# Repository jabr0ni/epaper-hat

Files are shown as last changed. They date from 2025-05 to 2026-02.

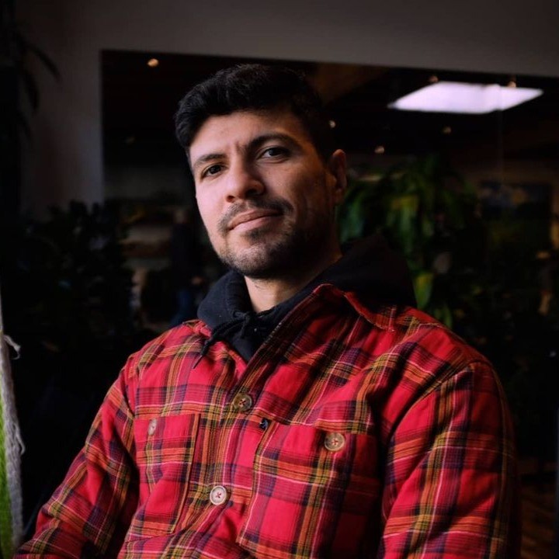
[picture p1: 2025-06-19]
Resources/1701730667659.jpg

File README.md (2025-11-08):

# E-Paper Business Card?

My idea is to create a type of business card with an e-paper display, where I can program some image/text content onto it. I also want to (in later revisions once the prototype is working) add a button on the back that can toggle to different images. Also have thought about adding one or two sensors (depending on space) such as a gyro and/or comms module. I plan on interfacing this with an STM32L4 MCU (have a Nucleo L433RC). Code for that has been started in this repo.

## PCB
This is my first PCB I've designed by myself from scratch, so any feedback is encouraged 😊
### Track layout


### Front + Back 3D



## BOM
| Reference | Qty | Value | Manufacturer Part No. |
|---|-----|---|---|
| C1, C2, C4, C5, C7, C9, C10 | 7 | 1u/50V | MBASU168AB5105KTNA01 |
| C3, C13 | 2 | 0.1u/50V | MAJCU168BB7104KTEA01 |
| C6, C8, C14 | 3 | 1u/25V | MAJCT168BB7105KTEA01 |
| C11, C12 | 2 | CL21A475KBQNNNE  | CL21A475KBQNNNE |
| D1, D2, D3 | 3 | MBR0530 | MBR0540T1G |
| J1 | 1 | Conn_01x08 | TSW-103-07-T-D |
| J2 | 1 | Conn_01x24 | MTSW-112-07-F-D-195 |
| J3 | 1 | SFV24R-1STBE1HLF | SFV24R-1STBE1HLF |
| L1 | 1 | L_Iron | LPS4018-104MRC |
| Q1 | 1 | Si1308EDL | SI1308EDL-T1-BE3 |
| Q2 | 1 | AO3401A | SSM3J340R,LF |
| Q3 | 1 | S8050 | SS8050DBU |
| R1 | 1 | 10k | CRCW060310K0FKEI |
| R2 | 1 | 3R | CRCW06033R00FKEAC |
| R3 | 1 | 1k | CRCW06031K00FKED |
| R6 | 1 | 1K | CRCW06031K00FKED |
| R7 | 1 | 10K | CRCW060310K0FKEI |
| R8, R9, R10 | 3 | 47K | CRCW060347K0FKED |
| R11 | 1 | 100K | CRCW0603100KFKEE |
| U1 | 1 | RT9193-33GB | RT9193-33GB |
| U2 | 1 | TXB0108PW | TXB0108PWR |
|----------------------------------------------------------------------------|

# Prototyped Boards
I recently had my custom PCB prototyped through [PCBWay](https://www.pcbway.com/), and I am very impressed with the overall quality and service. From the start, their customer support was excellent—clear, responsive, and proactive in keeping me updated on the progress of my order. It was reassuring to receive regular communication at each stage of the process, from file checks through to production and shipping.

The boards themselves came out great. The soldering work is clean, precise, and of consistently high quality. I inspected the joints and pads closely, and everything was well aligned with no visible defects or irregularities. The overall finish of the boards, from the silkscreen to the copper traces, is sharp and professional. It’s clear that PCBWay places strong emphasis on both manufacturing quality and attention to detail.

What stood out most to me was how smooth the experience was. Even as a prototype run, the boards feel production-ready, giving me confidence to move forward with testing and further development. For anyone looking for reliable PCB prototyping with excellent communication and workmanship, I would highly recommend PCBWay. I’ll definitely be returning for future projects.




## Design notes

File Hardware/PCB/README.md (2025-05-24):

# epaper-hat
PCB breakout board for e-paper module

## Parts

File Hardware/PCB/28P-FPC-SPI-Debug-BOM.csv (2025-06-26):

Reference | Qty | Value | DNP | Exclude from BOM | Exclude from Board | Footprint | Datasheet | Mouser No: | Mfr. No:
C1,C2,C4,C5,C7,C9,C10 | 7 | 1u/50V |  |  |  | capacitors-cam:CAPC2012X140N |  | 963-BASU168AB5105KT | MBASU168AB5105KTNA01
C3,C13 | 2 | 0.1u/50V |  |  |  | capacitors-cam:CAPC2012X140N |  | 963-MAJCU168BB7104KT | MAJCU168BB7104KTEA01
C6,C8,C14 | 3 | 1u/25V |  |  |  | capacitors-cam:CAPC1608X90N |  | 963-MAJCT168BB7105KT | MAJCT168BB7105KTEA01
C11,C12 | 2 | CL21A475KBQNNNE |  |  |  | capacitors-cam:CAPC2012X140N |  | 187-CL21A475KBQNNNE | CL21A475KBQNNNE
D1,D2,D3 | 3 | MBR0530 |  |  |  | Diode_SMD:D_SOD-123 | http://www.mccsemi.com/up_pdf/MBR0520~MBR0580(SOD123).pdf | 863-MBR0540T1G | MBR0540T1G
J1 | 1 | Conn_01x08 |  |  |  | Connector_Samtec_HLE_THT:Samtec_HLE-104-02-xx-DV-TE_2x04_P2.54mm_Horizontal | ~ | 200-TSW10307TD | TSW-103-07-T-D
J2 | 1 | Conn_01x24 |  |  |  | Connector_PinHeader_2.54mm:PinHeader_2x12_P2.54mm_Vertical | ~ | 200-MTSW-11207FD195 | MTSW-112-07-F-D-195
J3 | 1 | SFV24R-1STBE1HLF |  |  |  | Connectors-cam:AMPHENOL_SFV24R-1STBE1HLF |  | 649-SFV24R-1STBE1HLF | SFV24R-1STBE1HLF
L1 | 1 | L_Iron |  |  |  | inductors:IND_LPS4018-104MRC | ~ | 994-LPS4018-104MRC | LPS4018-104MRC
Q1 | 1 | Si1308EDL |  |  |  | Package_TO_SOT_SMD:SOT-323_SC-70 | https://www.vishay.com/docs/63399/si1308edl.pdf | 78-SI1308EDL-T1-BE3 | SI1308EDL-T1-BE3
Q2 | 1 | AO3401A |  |  |  | Package_TO_SOT_SMD:SOT-23 | http://www.aosmd.com/pdfs/datasheet/AO3401A.pdf | 757-SSM3J340RLF | SSM3J340R,LF
Q3 | 1 | S8050 |  |  |  | Package_TO_SOT_THT:TO-92_Inline | http://www.unisonic.com.tw/datasheet/S8050.pdf | 512-SS8050DBU | SS8050DBU
R1 | 1 | 10k |  |  |  | Resistor_SMD:R_0603_1608Metric_Pad0.98x0.95mm_HandSolder | ~ | 71-CRCW060347K0FKED | CRCW060310K0FKEI
R2 | 1 | 3R |  |  |  | Resistor_SMD:R_0603_1608Metric_Pad0.98x0.95mm_HandSolder | ~ | 71-CRCW060310K0FKEI | CRCW06033R00FKEAC
R3 | 1 | 1k |  |  |  | Resistor_SMD:R_0603_1608Metric_Pad0.98x0.95mm_HandSolder | ~ | 71-CRCW0603100KFKEE | CRCW06031K00FKED
R6 | 1 | 1K |  |  |  | Resistor_SMD:R_0603_1608Metric_Pad0.98x0.95mm_HandSolder | ~ | 71-CRCW06031K00FKED | CRCW06031K00FKED
R7 | 1 | 10K |  |  |  | Resistor_SMD:R_0603_1608Metric_Pad0.98x0.95mm_HandSolder | ~ | 71-CRCW06033R00FKEAC | CRCW060310K0FKEI
R8,R9,R10 | 3 | 47K |  |  |  | Resistor_SMD:R_0603_1608Metric_Pad0.98x0.95mm_HandSolder | ~ | 71-CRCW060347K0FKED | CRCW060347K0FKED
R11 | 1 | 100K |  |  |  | Resistor_SMD:R_0603_1608Metric_Pad0.98x0.95mm_HandSolder | ~ | 71-CRCW0603100KFKEE | CRCW0603100KFKEE
U1 | 1 | RT9193-33GB |  |  |  | VoltageRegulators:SOT94P279X129-5N |  | 835-RT9193-33GB | RT9193-33GB
U2 | 1 | TXB0108PW |  |  |  | Package_SO:TSSOP-20_4.4x6.5mm_P0.65mm | http://www.ti.com/lit/ds/symlink/txb0108.pdf | 595-TXB0108PWR | TXB0108PWR

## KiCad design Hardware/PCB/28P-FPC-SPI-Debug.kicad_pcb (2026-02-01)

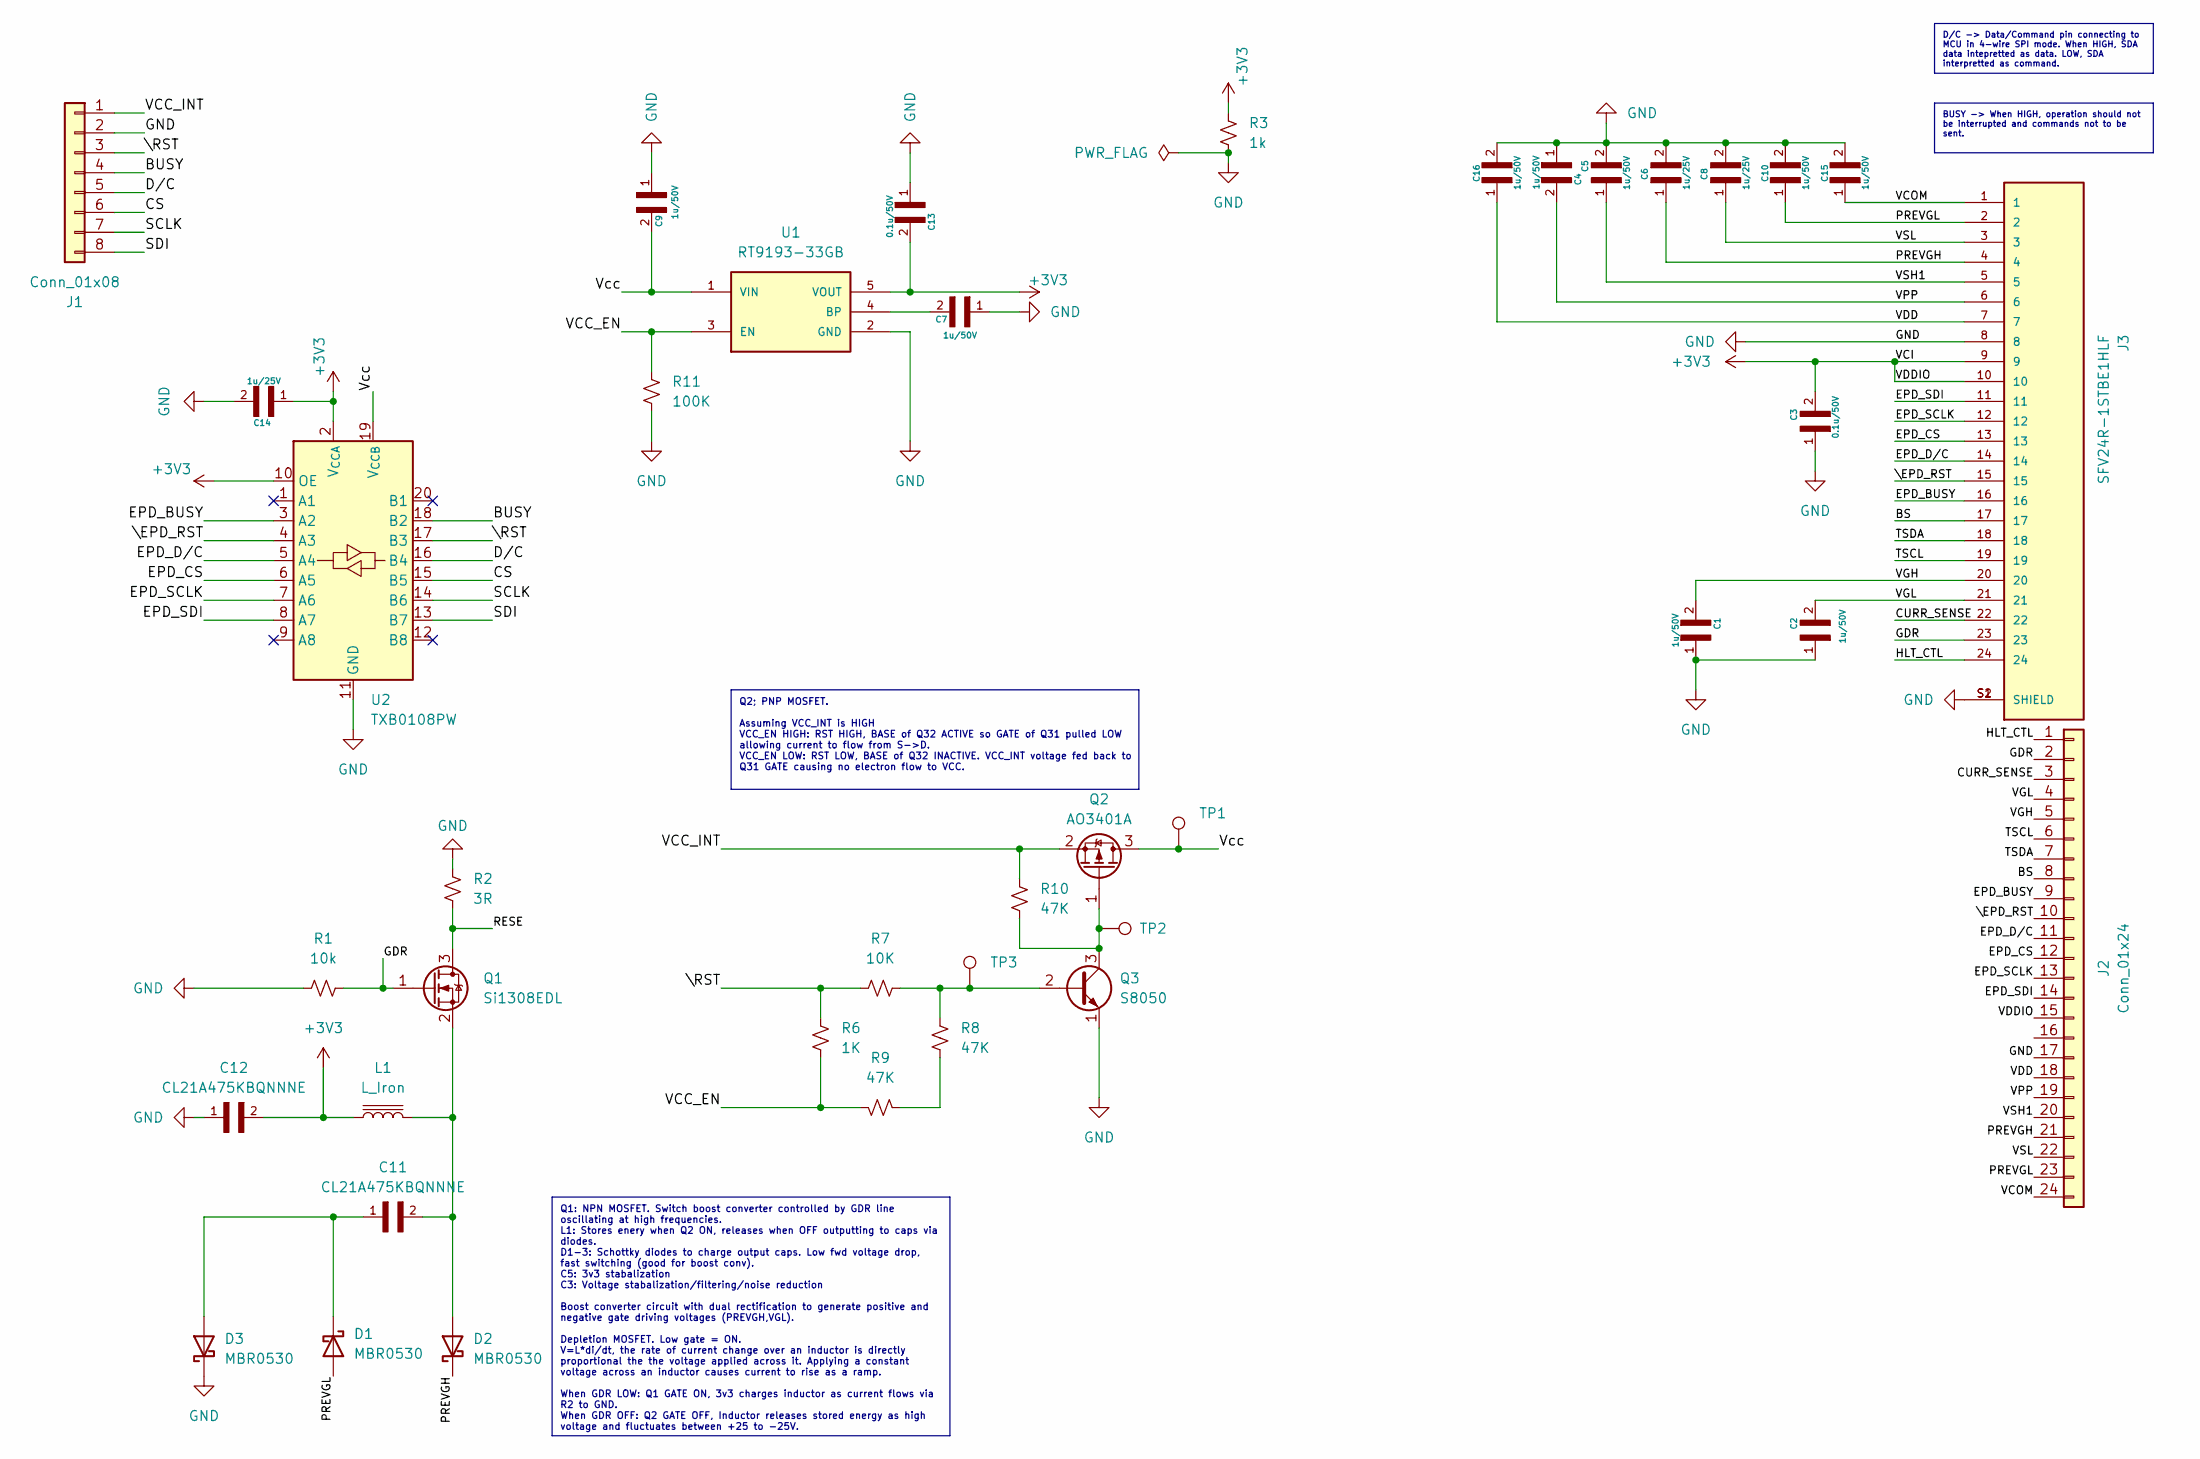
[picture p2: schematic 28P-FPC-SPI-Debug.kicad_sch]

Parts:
C1, C2, C4, C5, C7, C9, C10, C15, C16: 1u/50V; C_0603_1608Metric_Pad1.08x0.95mm_HandSolder; PARTREV NA
C3, C13: 0.1u/50V; C_0603_1608Metric_Pad1.08x0.95mm_HandSolder; PARTREV NA
C6, C8, C14: 1u/25V; CAPC1608X90N; PARTREV APR.09.2024
C11, C12: CL21A475KBQNNNE; C_0805_2012Metric_Pad1.18x1.45mm_HandSolder
D1, D2, D3: MBR0530; D_SOD-123
J1: Conn_01x08; PinHeader_1x08_P2.54mm_Vertical
J2: Conn_01x24; PinHeader_2x12_P2.54mm_Vertical
J3: SFV24R-1STBE1HLF; GCT_FFC2B28-24-G; PARTREV A
L1: L_Iron; IND_LPS4018-104MRC
Q1: Si1308EDL; SOT-323_SC-70
Q2: AO3401A; SOT-23
Q3: S8050
R1: 10k; R_0603_1608Metric_Pad0.98x0.95mm_HandSolder
R2: 3R; R_0603_1608Metric_Pad0.98x0.95mm_HandSolder
R3: 1k; R_0603_1608Metric_Pad0.98x0.95mm_HandSolder
R6: 1K; R_0603_1608Metric_Pad0.98x0.95mm_HandSolder
R7: 10K; R_0603_1608Metric_Pad0.98x0.95mm_HandSolder
R8, R9, R10: 47K; R_0603_1608Metric_Pad0.98x0.95mm_HandSolder
R11: 100K; R_0603_1608Metric_Pad0.98x0.95mm_HandSolder
TP1, TP2, TP3: TestPoint_THTPad_1.0x1.0mm_Drill0.5mm
U1: RT9193-33GB; SOT94P279X129-5N
U2: TXB0108PW; TSSOP-20_4.4x6.5mm_P0.65mm

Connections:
+3V3: C3.2, C12.2, C13.2, C14.1, J2.15, J3.9, J3.10, L1.1, R3.2, U1.5 (VOUT), U2.2 (V_{CCA}), U2.10 (OE)
/BS: J2.8, J3.17
/BUSY: J1.4, U2.18 (B2)
/CS: J1.6, U2.15 (B5)
/CURR_SENSE: J2.3, J3.22
/D/C: J1.5, U2.16 (B4)
/EPD_BUSY: J2.9, J3.16, U2.3 (A2)
/EPD_CS: J2.12, J3.13, U2.6 (A5)
/EPD_D/C: J2.11, J3.14, U2.5 (A4)
/EPD_SCLK: J2.13, J3.12, U2.7 (A6)
/EPD_SDI: J2.14, J3.11, U2.8 (A7)
/GDR: J2.2, J3.23, Q1.1 (G), R1.2
/HLT_CTL: J2.1, J3.24
/PREVGH: C6.1, D2.1 (K), J2.21, J3.4
/PREVGL: C10.1, D1.2 (A), J2.23, J3.2
/RESE: Q1.3 (D), R2.1
/SCLK: J1.7, U2.14 (B6)
/SDI: J1.8, U2.13 (B7)
/TSCL: J2.6, J3.19
/TSDA: J2.7, J3.18
/VCC_EN: R6.2, R9.1, R11.1, U1.3 (EN)
/VCC_INT: J1.1, Q2.2 (S), R10.2
/VCOM: C15.1, J2.24, J3.1
/VDD: C16.1, J2.18, J3.7
/VGH: C1.2, J2.5, J3.20
/VGL: C2.2, J2.4, J3.21
/VPP: C4.2, J2.19, J3.6
/VSH1: C5.1, J2.20, J3.5
/VSL: C8.1, J2.22, J3.3
/Vcc: C9.2, Q2.3 (D), TP1.1, U1.1 (VIN), U2.19 (V_{CCB})
/\EPD_RST: J2.10, J3.15, U2.4 (A3)
/\RST: J1.3, R6.1, R7.2, U2.17 (B3)
GND: C1.1, C2.1, C3.1, C4.1, C5.2, C6.2, C7.1, C8.2, C9.1, C10.2, C12.1, C13.1, C14.2, C15.2, C16.2, D3.1 (K), J1.2, J2.17, J3.8, J3.S1 (SHIELD), J3.S2 (SHIELD), Q3.1 (E), R1.1, R2.2, R3.1, R11.2, U1.2 (GND), U2.11 (GND)
unnamed: C11.1, D1.1 (K), D3.2 (A)
unnamed: C11.2, D2.2 (A), L1.2, Q1.2 (S)
unnamed: Q2.1 (G), Q3.3 (C), R10.1, TP2.1
unnamed: Q3.2 (B), R7.1, R8.2, TP3.1
unnamed: R8.1, R9.2
unnamed: C7.2, U1.4 (BP)

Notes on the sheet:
D/C -> Data/Command pin connecting to MCU in 4-wire SPI mode. When HIGH, SDA data intepretted as data. LOW, SDA interpretted as command.
Q1: NPN MOSFET. Switch boost converter controlled by GDR line oscillating at high frequencies. L1: Stores enery when Q2 ON, releases when OFF outputting to caps via diodes. D1-3: Schottky diodes to charge output caps. Low fwd voltage drop, fast switching (good for boost conv). C5: 3v3 stabalization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
BUSY -> When HIGH, operation should not be interrupted and commands not to be sent.
Q2; PNP MOSFET. Assuming VCC_INT is HIGH VCC_EN HIGH: RST HIGH, BASE of Q32 ACTIVE so GATE of Q31 pulled LOW allowing current to flow from S->D. VCC_EN LOW: RST LOW, BASE of Q32 INACTIVE. VCC_INT voltage fed back to Q31 GATE causing no electron flow to VCC.

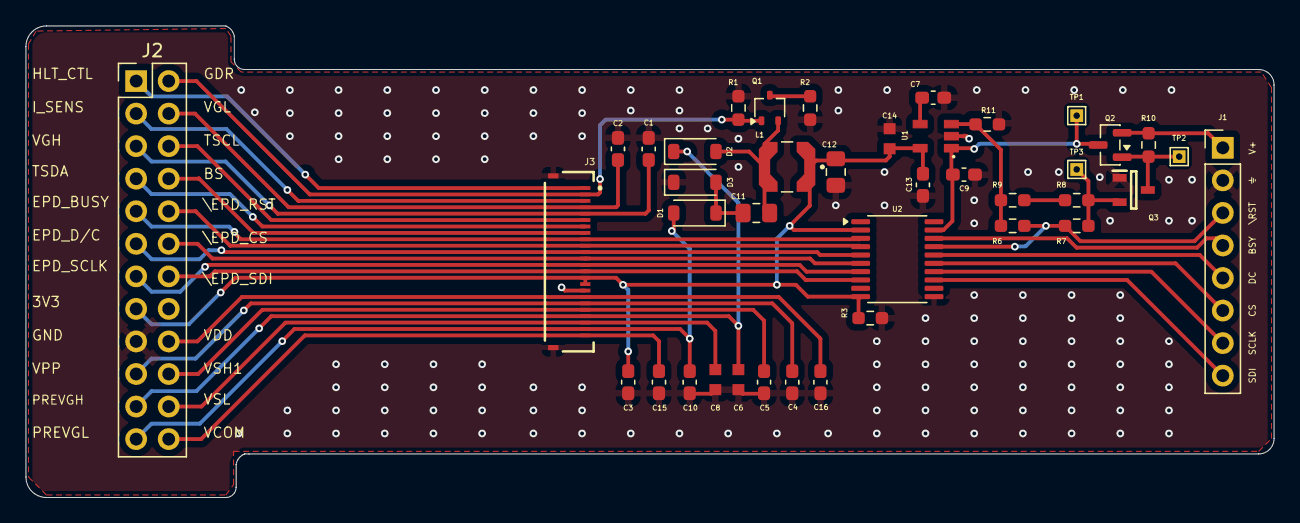
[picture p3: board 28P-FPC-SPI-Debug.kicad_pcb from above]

Board: 2 copper layers, 97.4 x 36.8 mm, 40 parts (0 on the bottom side), 39 nets.

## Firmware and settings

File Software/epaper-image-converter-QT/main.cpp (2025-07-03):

#include "mainwindow.h"

#include <QApplication>
#include <QLocale>
#include <QTranslator>
#include <qlabel.h>

int main(int argc, char *argv[])
{
    QApplication a(argc, argv);

    QTranslator translator;
    const QStringList uiLanguages = QLocale::system().uiLanguages();
    for (const QString &locale : uiLanguages) {
        const QString baseName = "epaper-image-converter_" + QLocale(locale).name();
        if (translator.load(":/i18n/" + baseName)) {
            a.installTranslator(&translator);
            break;
        }
    }


    MainWindow w;
    w.setWindowTitle(QObject::tr("MAKE ME IMAGEEEEEE"));
    w.show();
    return a.exec();
}

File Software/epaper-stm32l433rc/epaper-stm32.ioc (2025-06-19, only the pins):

Mcu.UserName=STM32L433RCTxP
PA2.GPIO_Label=USART_TX
PA2.Signal=USART2_TX
PA3.GPIO_Label=USART_RX
PA3.Signal=USART2_RX
PA4.GPIO_Label=SMPS_EN [ADP5301ACBZ_VEN]
PA4.Signal=GPIO_Output
PA5.GPIO_Label=SMPS_V1
PA5.Signal=GPIO_Output
PA6.GPIO_Label=SMPS_PG [ADP5301ACBZ_OUTOK]
PA6.Signal=GPIO_Input
PA7.GPIO_Label=SMPS_SW [TS3A44159PWR_IN1_2]
PA7.Signal=GPIO_Output
PB13.GPIO_Label=LD4 [green Led]
PB13.Signal=GPIO_Output
PC13.GPIO_Label=B1 [Blue PushButton]
PC13.Signal=GPXTI13

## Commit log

2025-05-24 First commit. Just putting this up here.
    [28P-FPC-SPI-Debug.kicad_pcb, 28P-FPC-SPI-Debug.kicad_sch]
2025-05-24 Added resources. Modified folder structure.
    [28P-FPC-SPI-Debug.kicad_pcb, 28P-FPC-SPI-Debug.kicad_sch]
2025-05-29 Modified power switch circuit and added note. Added note for boost converter.
    [28P-FPC-SPI-Debug.kicad_sch]
2025-05-30 Modified power enable circuit to v2.2 ref design and added note.
    [28P-FPC-SPI-Debug.kicad_pcb, 28P-FPC-SPI-Debug.kicad_sch]
2025-05-31 Added voltage level shifter TXB018PW
    [28P-FPC-SPI-Debug.kicad_pcb, 28P-FPC-SPI-Debug.kicad_sch]
2025-06-08 Added nets for TXB018PW. Resized PCB to size of 2.13in e-paper display with ~5mm excess on edges. Questionable part placement start.
    [28P-FPC-SPI-Debug.kicad_pcb, 28P-FPC-SPI-Debug.kicad_sch]
2025-06-08 track placement, parts moved, nightmare fuel.
    [28P-FPC-SPI-Debug.kicad_pcb]
2025-06-08 track placement
    [28P-FPC-SPI-Debug.kicad_pcb, 28P-FPC-SPI-Debug.kicad_sch]
2025-06-12 Added breakout 28pin header for debugging. Track cleanup. Changed 0603 footprint due to clearance violations. Increased board size to fit header.
    [28P-FPC-SPI-Debug.kicad_pcb, 28P-FPC-SPI-Debug.kicad_sch]
2025-06-13 Moved some parts. Cleared ERC errors and warnings. Ready?
    [28P-FPC-SPI-Debug.kicad_pcb, 28P-FPC-SPI-Debug.kicad_sch]
2025-06-19 Mouser BOM
    [28P-FPC-SPI-Debug-BOM.csv]
2025-06-19 Added STM32 NUCLEO-L433RC project with basic pin assignments to J1 jumper on PCB for project start. Modified folder structure.
    [28P-FPC-SPI-Debug-BOM.csv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]
2025-06-26 Added waveshare submodule
    [28P-FPC-SPI-Debug-BOM.csv]
2025-07-03 First commit for QT6 image converter app. Basic UI with load image push button, and image display in window panel.
2025-10-17 Modified J1 footprint to 1.7mm through hole. Added copper pours and GND via stitching for thermal relief. Plus some other stuff I can't remember. E-paper waveshare libs added to STM32 project. Projec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
    [28P-FPC-SPI-Debug.kicad_pcb, 28P-FPC-SPI-Debug.kicad_sch]
2025-10-17 Missed files added from prev commit.
    [epaper-stm32.ioc]
2025-10-17 removed waveshare repo. renamed stm32 project folder.
2025-10-17 Revise project description and PCB feedback request
    Updated the README to clarify the project idea and PCB design experience.
2025-11-08 Mirror pins on FPC connector. Reposition components. Copper pours
    [28P-FPC-SPI-Debug.kicad_pcb, 28P-FPC-SPI-Debug.kicad_sch]
2025-11-08 Modified J3 FPC connector to top bottom connector FFC2B28-24-G.
    [28P-FPC-SPI-Debug.kicad_pcb, 28P-FPC-SPI-Debug.kicad_sch]
2026-01-26 Modified FPC capacitor footprints to 0603 and 0805 due to production issues.
    [28P-FPC-SPI-Debug-B_Cu.gbl, 28P-FPC-SPI-Debug-B_Mask.gbs, 28P-FPC-SPI-Debug-B_Paste.gbp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]
2026-01-26 Modified J2 to THT due to parts issue.
    [28P-FPC-SPI-Debug.kicad_pcb]
2026-02-01 Font size changes on some silkscreen prints. Footprint assignment mods for consistency.
    [28P-FPC-SPI-Debug.kicad_pcb]
